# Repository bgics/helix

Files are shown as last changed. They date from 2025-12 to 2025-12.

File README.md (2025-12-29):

# Helix

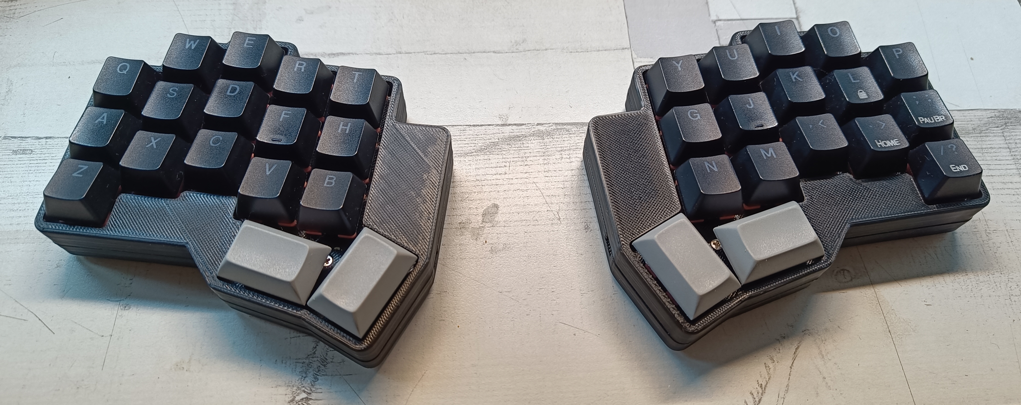
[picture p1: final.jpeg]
Helix Keyboard

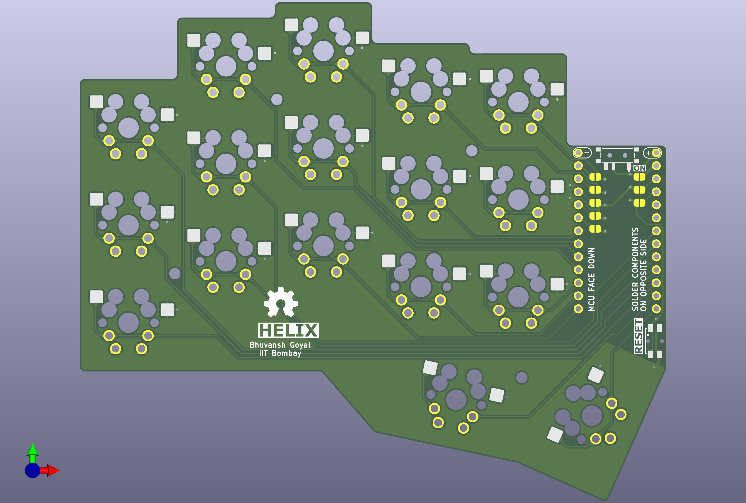
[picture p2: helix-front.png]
Helix PCB


Helix is a **34-key split wireless keyboard** designed as a compact, ergonomic daily driver.  
It uses a reversible PCB, hot-swap sockets, and runs ZMK firmware on nice!nano controllers.

This repository contains **all hardware, PCB, and mechanical design files** required to build the keyboard.

---

## Features

- 34-key split layout
- Reversible PCB (same PCB for left and right halves)
- Wireless (nice!nano + ZMK)
- Hot-swap MX switches

---

## Repository Structure

### Root
Main KiCad project files:
- `helix.kicad_pcb`
- `helix.kicad_sch`
- `helix.kicad_pro`

### `footprints/`
Custom KiCad footprints used in the PCB.

### `symbols/`
Custom schematic symbols.

### `3d_models/`
STEP / 3D models used for PCB visualization and mechanical checks.

### `case/`
STL files for the keyboard case.

### `gerber/`
Final Gerber files for PCB manufacturing.

---

## Build Guide

A step-by-step build guide is available here:

👉 **[Build Guide](buildguide.md)**

---

## Firmware

Firmware configuration lives in a separate repository:

👉 https://github.com/bgics/zmk-helix

---

## Notes

- This is a **reversible PCB**, so the same PCB is used for both left and right halves.
- Battery size depends on the case — check the STL files before ordering batteries.

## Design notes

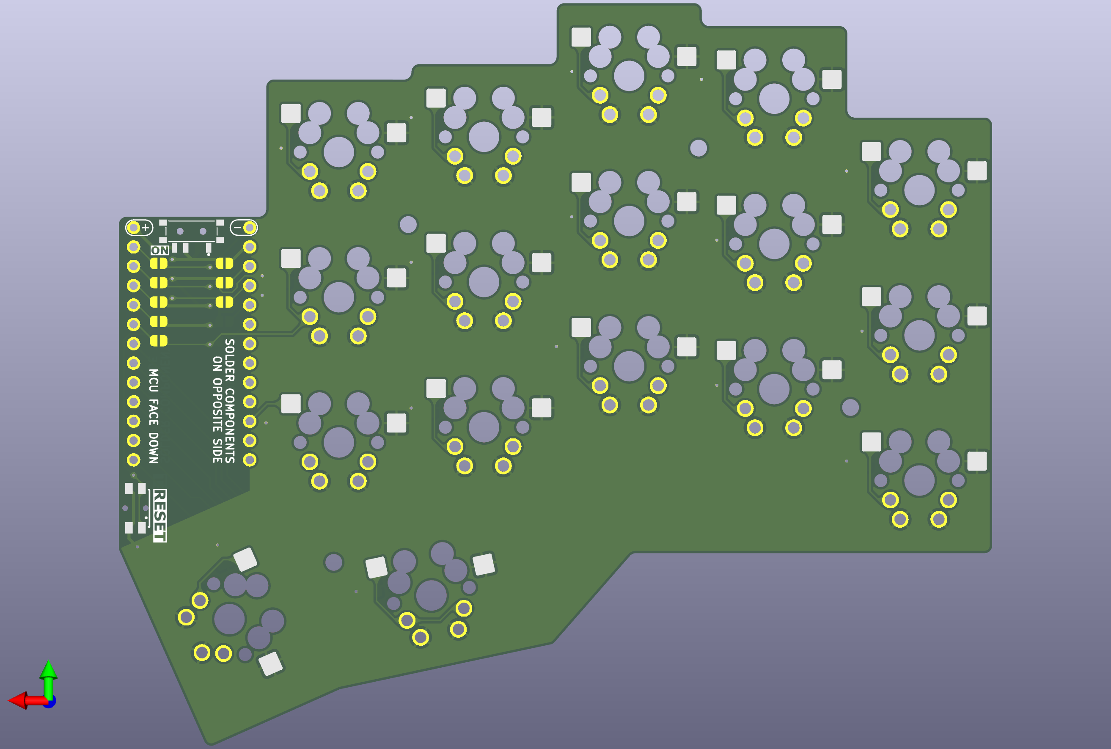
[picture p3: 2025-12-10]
helix-back.png

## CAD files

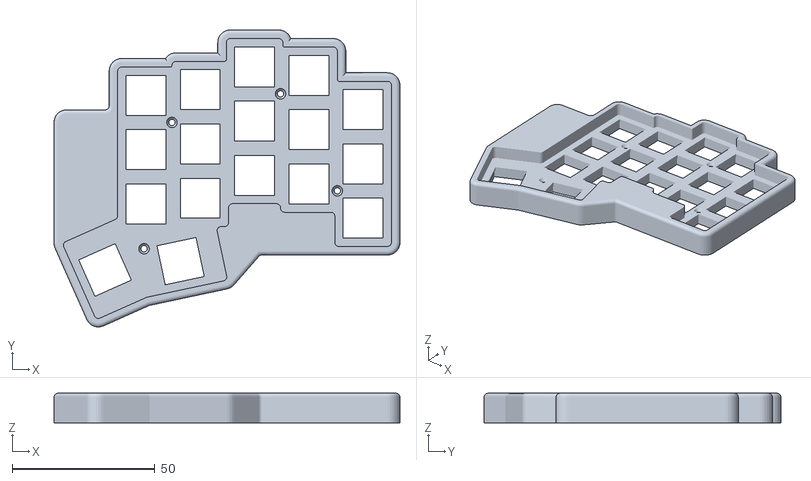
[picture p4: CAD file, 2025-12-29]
case/right_top.stl
121.4 x 104.2 x 10.4

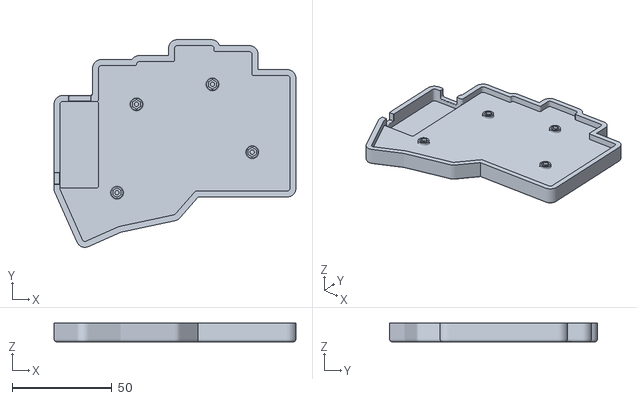
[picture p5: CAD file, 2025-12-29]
case/right_bottom.stl
121.4 x 104.2 x 9.40

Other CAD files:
case/left_top.stl
case/left_bottom.stl

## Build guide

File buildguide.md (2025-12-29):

# Helix Build Guide

This guide walks through assembling one half of the Helix keyboard.  
Repeat the same steps for the other half.

> **Important:**  
> Helix uses a **reversible PCB**. The same PCB is used for both left and right sides.

---

## Assembly Order (Recommended)

### 1. Solder the MCU (nice!nano)

- Solder the **MCU face-down** onto the PCB.
- Make sure orientation is correct before soldering.
- **Do NOT solder the top row of MCU pins. Leave them unconnected.**
- Double-check pin alignment — fixing this later is painful.

---

### 2. Solder Small Components (Opposite Side)

On the **opposite side of where the MCU is soldered**, solder the following:

- Reset button
- Power slide switch
- Jumpers

⚠️ All of these **must be on the opposite side of the MCU**.

---

### 3. Solder the Battery

- The battery **+ and − pads are clearly labeled on the PCB**.
- You can use **any LiPo battery**, but:
  - Check the **battery slot size in the case STL** to ensure it fits.
- **Before soldering the battery**, set the power switch to **OFF**.

---

### 4. Solder Hot-Swap Sockets

- Solder all hot-swap sockets on the **opposite side of the MCU**.
- Make sure they sit flat — uneven sockets will cause switch fit issues.

---

## Case Assembly

### 5. Insert Hex Nuts

- Insert **4 × M2 hex nuts per side** into the bottom case.
- The fit is tight; adding **a small amount of adhesive** is recommended.
  - Epoxy works well.
  - Avoid blocking the screw holes.

---

### 6. Final Assembly

1. Place the PCB into the bottom case  
   - MCU should be on the **top side**
2. Place the top case
3. Insert **4 × M2 countersunk (CSK) screws**
4. Tighten evenly

---

### 7. Switches & Keycaps

- Insert switches
- Add keycaps

Repeat the entire process for the other half.

---

## Done

Flash firmware, pair the halves, and you’re good to go.

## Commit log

2025-12-29 added case stl files and updated keyboard image
    [left_bottom.stl, left_top.stl, right_bottom.stl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]
2025-12-29 added gerber files
2025-12-29 Add Helix keyboard assembly guide
    This document provides a comprehensive guide for assembling one half of the Helix keyboard, detailing the necessary steps and components involved in the process.
